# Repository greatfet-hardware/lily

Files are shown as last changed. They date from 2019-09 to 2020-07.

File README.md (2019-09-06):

# Lily
an RF power detecting GreatFET neighbor

Required KiCad dependency:

https://github.com/greatscottgadgets/gsg-kicad-lib

If you are using git, the preferred way to install gsg-kicad-lib is to use the
submodule:

```
git submodule init && git submodule update
```

## potential ICs
* LTC5507 100 kHz - 1 GHz
* HMC1120LP4E DC - 3.9 GHz
* MAX2016 LF - 2.5 GHz dual channel
* ADL5904 DC - 6 GHz
* AD8363 DC - 6 GHz
* HMC909LP4E DC - 5.8 GHz

## Pin usage

signal  | pin     | alt1  | alt2
--------|---------|-------|-----
VOUT    | J2.05   | J2.09 | J2.16
ENBL    | J1.03   | J1.04 | J1.05
RST     | GND     | J1.20 | J1.22
Q       |         | J2.17 | J2.18
Q bar   |         | J2.30 | J2.31

## Initial calibration data
Calibration data was taken by driving the RF input of Lily with a function generator creating a 10MHz sine wave at various amplitudes (VPP). The analog voltage output (VRMS) was measured with an oscilloscope and the ADC was used to convert VRMS into a digital measurement. Driving Lily with an input of VPP = 4V resulted in Lily drawing 4mA of supply current. The input should not exceed VPP = 5.62V in order to avoid damaging the board.

VPP     | VRMS    | ADC
--------|---------|-------
10mV    | 25mV    | 7
50mV    | 0.258V  | 84
0.1V    | 0.478V  | 155
0.2V    | 0.697V  | 227
0.3V    | 0.830V  | 267
0.5V    | 0.988V  | 317
1V      | 1.2V    | 386
2V      | 1.4V    | 454
3V      | 1.57V   | 494
4V      | 1.66V   | 524

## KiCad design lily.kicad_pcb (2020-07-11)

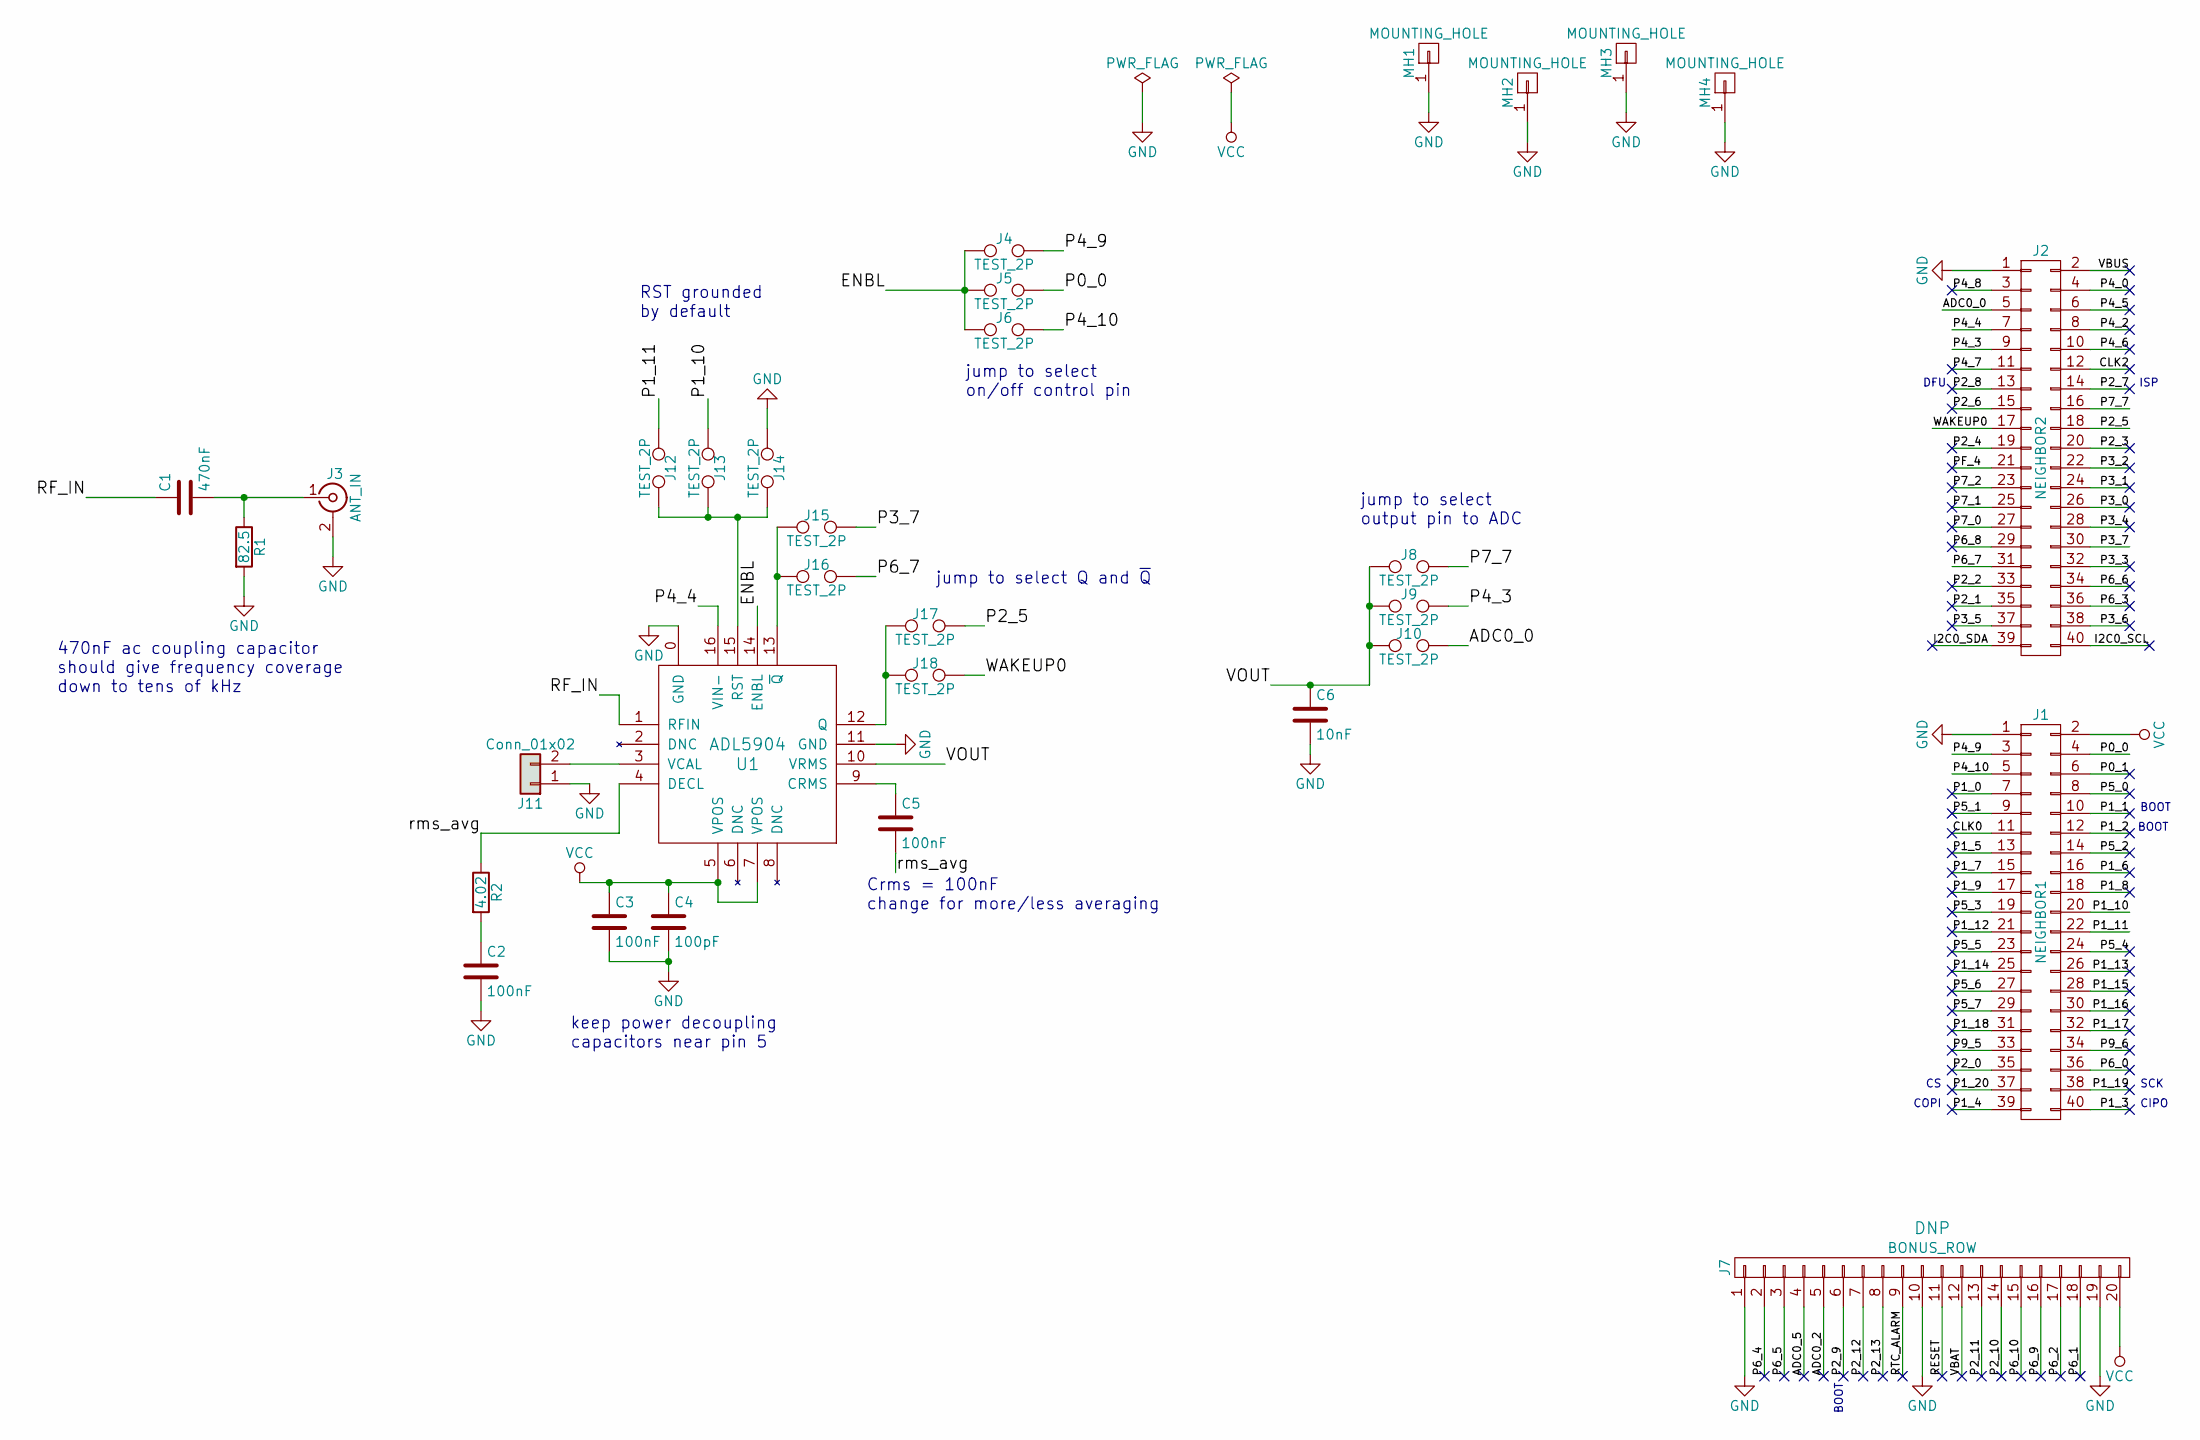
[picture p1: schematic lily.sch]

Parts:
C1: 470nF; 0603; Part Number GRM188R61H474KA12D
C2, C3, C5: 100nF; 0603; Part Number GCM188L81H104KA57D
C4: 100pF; 0603; Part Number GQM1885C1H101JB01D
C6: 10nF; 0603; Part Number 885012206065
J1: NEIGHBOR1; HEADER-2x20; Part Number SSQ-120-23-G-D
J2: NEIGHBOR2; HEADER-2x20; Part Number SSQ-120-23-G-D
J3: ANT_IN; SMA-EDGE; Part Number CONREVSMA003.031
J4, J5, J6, J8, J9, J10, J12, J13, J14, J15, J16, J17, J18: TEST_2P; 0603-JUMPER
J7: BONUS_ROW; HEADER-1x20; Part Number SSQ-120-23-G-S
J11: Conn_01x02; Pin_Header_Straight_1x02_Pitch2.54mm
MH1, MH2, MH3, MH4: MOUNTING_HOLE; HOLE126MIL-COPPER
R1: 82.5; 0603; Part Number RMCF0603FT82R5
R2: 4.02; 0603; Part Number RMCF0603FT4R02
U1: ADL5904; QFN16-3; Part Number ADL5904ACPZN-R7

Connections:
/ADC0_0: J2.5, J10.2
/ADC0_2: J7.5
/ADC0_5: J7.4
/CLK0: J1.11
/CLK2: J2.12
/ENBL: J4.1, J5.1, J6.1, U1.14 (ENBL)
/I2C0_SCL: J2.40
/I2C0_SDA: J2.39
/P0_0: J1.4, J5.2
/P0_1: J1.6
/P1_0: J1.7
/P1_1: J1.10
/P1_2: J1.12
/P1_3: J1.40
/P1_4: J1.39
/P1_5: J1.13
/P1_6: J1.16
/P1_7: J1.15
/P1_8: J1.18
/P1_9: J1.17
/P1_10: J1.20, J13.1
/P1_11: J1.22, J12.1
/P1_12: J1.21
/P1_13: J1.26
/P1_14: J1.25
/P1_15: J1.28
/P1_16: J1.30
/P1_17: J1.32
/P1_18: J1.31
/P1_19: J1.38
/P1_20: J1.37
/P2_0: J1.35
/P2_1: J2.35
/P2_2: J2.33
/P2_3: J2.20
/P2_4: J2.19
/P2_5: J2.18, J17.2
/P2_6: J2.15
/P2_7: J2.14
/P2_8: J2.13
/P2_9: J7.6
/P2_10: J7.14
/P2_11: J7.13
/P2_12: J7.7
/P2_13: J7.8
/P3_0: J2.26
/P3_1: J2.24
/P3_2: J2.22
/P3_3: J2.32
/P3_4: J2.28
/P3_5: J2.37
/P3_6: J2.38
/P3_7: J2.30, J15.2
/P4_0: J2.4
/P4_2: J2.8
/P4_3: J2.9, J9.2
/P4_4: J2.7, U1.16 (VIN-)
/P4_5: J2.6
/P4_6: J2.10
/P4_7: J2.11
/P4_8: J2.3
/P4_9: J1.3, J4.2
/P4_10: J1.5, J6.2
/P5_0: J1.8
/P5_1: J1.9
/P5_2: J1.14
/P5_3: J1.19
/P5_4: J1.24
/P5_5: J1.23
/P5_6: J1.27
/P5_7: J1.29
/P6_0: J1.36
/P6_1: J7.18
/P6_2: J7.17
/P6_3: J2.36
/P6_4: J7.2
/P6_5: J7.3
/P6_6: J2.34
/P6_7: J2.31, J16.2
/P6_8: J2.29
/P6_9: J7.16
/P6_10: J7.15
/P7_0: J2.27
/P7_1: J2.25
/P7_2: J2.23
/P7_7: J2.16, J8.2
/P9_5: J1.33
/P9_6: J1.34
/PF_4: J2.21
/RESET: J7.11
/RF_IN: C1.1, U1.1 (RFIN)
/RTC_ALARM: J7.9
/VBAT: J7.12
/VBUS: J2.2
/VOUT: C6.1, J8.1, J9.1, J10.1, U1.10 (VRMS)
/WAKEUP0: J2.17, J18.2
/rms_avg: C5.2, R2.1, U1.4 (DECL)
GND: C2.2, C3.2, C4.2, C6.2, J1.1, J2.1, J3.2 (Ext), J7.1, J7.10, J7.19, J11.1, J14.1, MH1.1, MH2.1, MH3.1, MH4.1, R1.2, U1.0 (GND), U1.11 (GND)
unnamed: C1.2, J3.1 (In), R1.1
unnamed: C2.1, R2.2
unnamed: C5.1, U1.9 (CRMS)
unnamed: J11.2, U1.3 (VCAL)
unnamed: J12.2, J13.2, J14.2, U1.15 (RST)
unnamed: J15.1, J16.1, U1.13 (~Q~)
unnamed: J17.1, J18.1, U1.12 (Q)
VCC: C3.1, C4.1, J1.2, J7.20, U1.5 (VPOS), U1.7 (VPOS)

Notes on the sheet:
CIPO
COPI
SCK
ISP
DFU
BOOT
jump to select output pin to ADC
jump to select on/off control pin
keep power decoupling capacitors near pin 5
470nF ac coupling capacitor should give frequency coverage down to tens of kHz
Crms = 100nF change for more/less averaging
RST grounded by default
jump to select Q and ~Q~

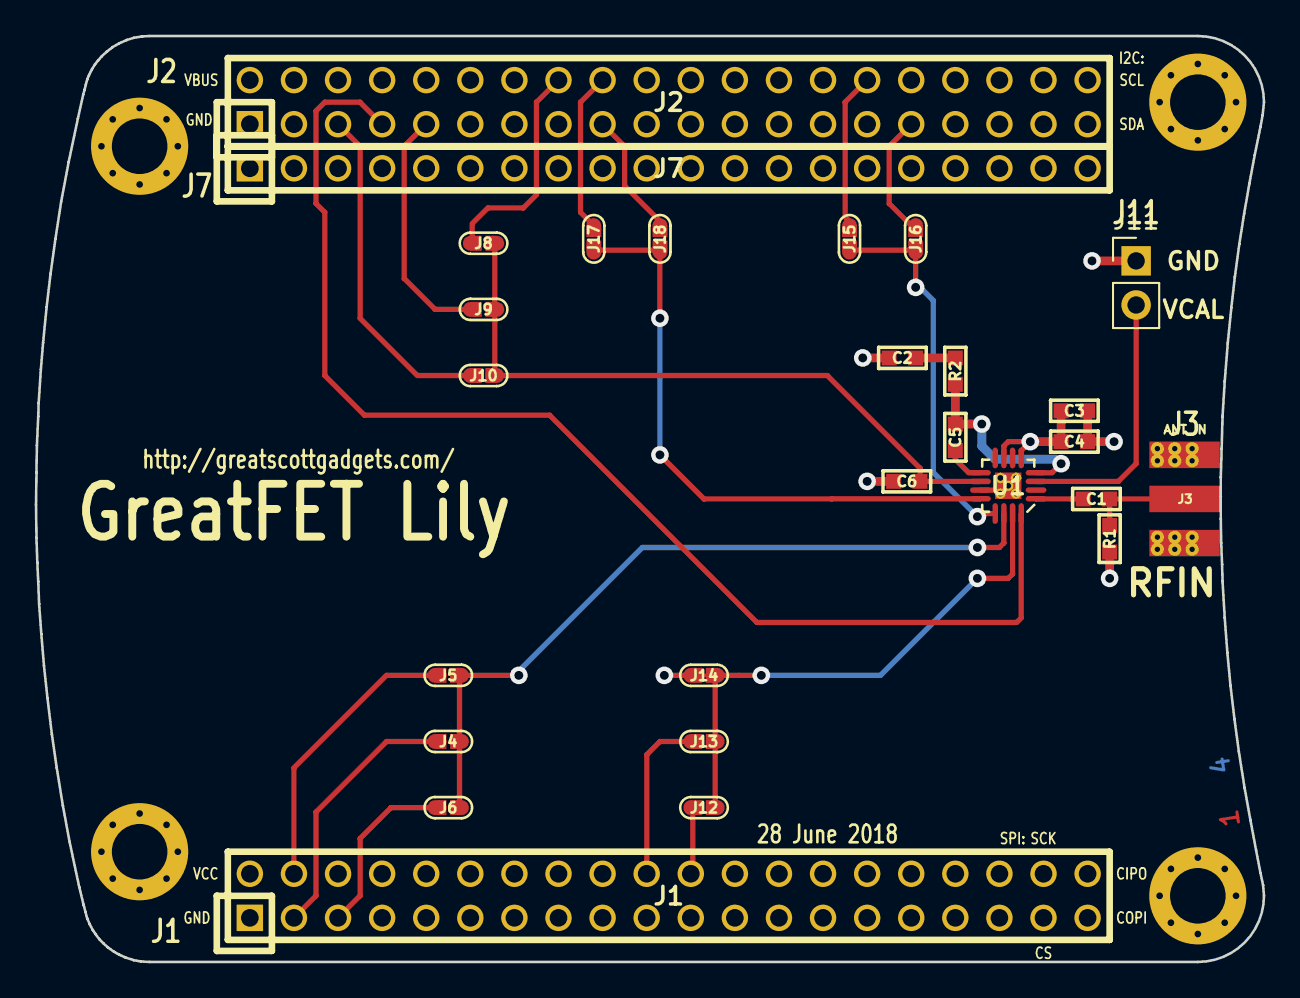
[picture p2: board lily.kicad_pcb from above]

Board: 4 copper layers, 70.7 x 53.3 mm, 31 parts (0 on the bottom side), 26 nets.

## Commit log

2019-05-27 split lily into separate repository
    [azalea.kicad_pcb, azalea.sch, begonia.kicad_pcb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]
2020-07-03 adopt OSHWA convention for SPI signal names https://www.oshwa.org/a-resolution-to-redefine-spi-signal-names
    [lily.kicad_pcb, lily.sch]

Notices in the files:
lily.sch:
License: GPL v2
